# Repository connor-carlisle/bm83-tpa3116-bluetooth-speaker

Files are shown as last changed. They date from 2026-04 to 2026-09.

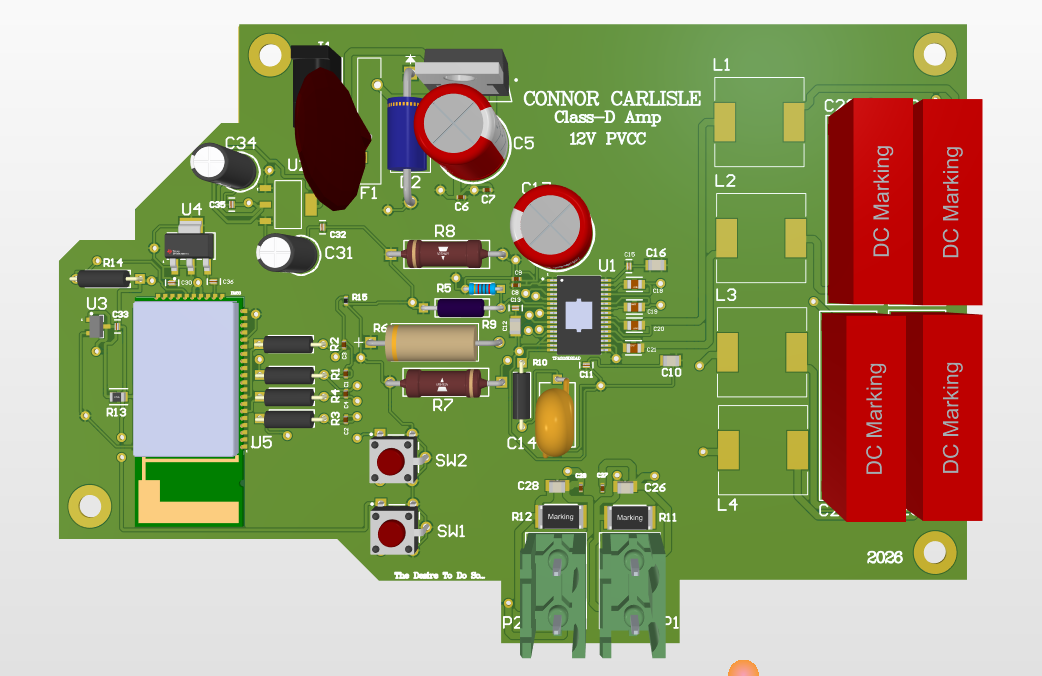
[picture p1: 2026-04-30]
images/PCB 3D Top View.png

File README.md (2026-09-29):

# Bluetooth Speaker — BM83 + TPA3116D2 Class D

A stereo Bluetooth speaker designed in Altium Designer around the **Microchip BM83** Bluetooth audio module and the **TI TPA3116D2DAD** Class D amplifier. Single-board design with a hierarchical schematic, mixed-signal grounding, and RF-aware antenna placement.

PCB 3D Top View

---

## Overview

This board is a fully integrated stereo Bluetooth speaker driver: it receives a Bluetooth audio stream, decodes it on the BM83 module, and drives a pair of speakers through a Class D amplifier — all on a single ~100 × 100 mm PCB.

The design is intentionally compact and inexpensive to fabricate (single-board, 2-layer, hand-solderable footprints throughout) while still respecting the discipline a mixed-signal RF audio board demands: clean separation of analog and high-current ground domains, careful output filtering on the Class D amplifier, and a defined antenna keep-out zone for the BM83's integrated chip antenna.

## Key specs

| Parameter | Value |
|---|---|
| Bluetooth module | Microchip BM83 (Bluetooth 5.0, A2DP / AVRCP) |
| Amplifier | TI TPA3116D2DAD — Class D, BTL stereo |
| Output power | Up to ~50 W/channel (supply-dependent) |
| Speaker configuration | Stereo, Bridge-Tied Load |
| Logic supply | Takes 12V PVCC input, 3.3 V regulator via LM1117-3.3 LDO + MCP111T-270E/TT reset supervisor for BM83|
| Board | 2-layer FR-4, ~100 × 100 mm |
| EDA | Altium Designer |

## Block diagram

  Power input ──┬──────────────────────► TPA3116D2 (Class D amp) ──► BTL LC filter ──► Speakers
                │
                └─► LM1117-3.3 LDO ──┬─► BM83 (Bluetooth audio) ──► (audio out to amp)
                                     │
                                     └─► MCP111T reset supervisor

## Design decisions

### Why the BM83
The BM83 is a fully-certified Bluetooth audio module — the alternative was building a Bluetooth stack on a bare BT chip, which is dramatically more work for a personal project and requires going through Bluetooth SIG certification. The BM83 ships with a complete stack, a stereo audio path, and an integrated chip antenna in a small footprint. The trade-off is less flexibility and a higher cost per unit, but it is the right choice for a single-board portfolio piece.

### Why the TPA3116D2DAD
Industry-standard Class D amplifier with strong documentation, stereo BTL configuration in a single chip, and well-understood thermal behavior. The DAD-suffix package (HTSSOP with PowerPad) is easier to hand-assemble than the alternative DAP package while still providing adequate thermal performance for the target output level.

### Power architecture
A single supply input feeds the TPA3116 directly and is regulated down to 3.3 V by an LM1117-3.3 LDO for the BM83. An MCP111T-270E/TT reset supervisor holds the BM83 in reset until the 3.3 V rail crosses its threshold, ensuring clean power-on-reset behavior. An LDO was chosen over a switcher for the BM83 supply specifically to avoid injecting switching noise into the Bluetooth radio's PLL.

### BTL output filter
The Class D switching outputs need an LC filter before reaching the speakers. Without one, you radiate the switching frequency directly through the speaker leads — which act as antennas — and you cause both EMI compliance problems and audible distortion. The filter is sized for the audio bandwidth and the target speaker impedance.

### Mixed-signal grounding
The board uses an **SGND / GND star ground** scheme: the analog return from the BM83 audio output and the high-current return from the speaker terminals are kept on separate copper pours and joined at a single point near the connector. Without this separation, speaker-current-induced ground bounce modulates the analog reference and shows up as audible noise in the amplified output.

### Antenna placement
The BM83's chip antenna is placed at the **board edge** with **copper pour exclusion** in the keep-out zone defined by the BM83 datasheet. Putting copper pour under or near the antenna detunes it and crushes the radiation pattern. This is one of those layout rules that's easy to miss but completely changes whether your Bluetooth actually works at usable range.

## Repository structure

```
.
├── README.md                       This file
├── LICENSE
├── altium/                         Raw Altium project source
├── outputs/
│   ├── gerbers/                    Manufacturing Gerbers + drill files (ZIP)
│   ├── bom/                        Bill of materials (CSV)
│   ├── pick-and-place/             Pick-and-place files
│   └── pdf/
│       ├── schematic.pdf           Browser-viewable schematic
│       └── fabrication-drawing.pdf Board outline and layer stack
├── docs/
│   ├── component-reference.md      Detailed component selection notes
│   └── design-notes.md             Extended design rationale
└── images/                         Renders and diagrams
```

## Viewing the design

Don't have Altium? You can still inspect everything:

- **[Schematic (PDF)](outputs/pdf/schematic.pdf)** — full hierarchical schematic
- **[Fabrication drawing (PDF)](outputs/pdf/fabrication-drawing.pdf)** — board outline, layer stack, mechanical dimensions
- **[Bill of materials](outputs/bom/)**
- **[3D renders](images/)**

To open the source files, clone the repo and open `altium/PCB1.PrjPcb` in Altium Designer (a free Altium Education license is available for students).

## Manufacturing

The Gerber set in `outputs/gerbers/` is fab-ready and tested-friendly with JLCPCB, PCBWay, and most North American fabs. Default specifications:

- 2-layer FR-4
- 1.6 mm thickness
- 1 oz copper
- HASL or ENIG finish

Most components are stocked at Digi-Key and Mouser. The BM83 has occasional supply constraints — check stock before placing an order.

## Status

- ✅ Design complete, schematic ERC clean
- ✅ Manufacturing outputs generated
- ✅ Prototype built
- 🔲 Bring-up and validation: output power, THD, idle noise

*Developed with AI assistance (Claude); design decisions and verification are my own.*

## Lessons learned

A few things that came out of this design that I'd carry forward to the next revision:

- **Reset supervisor is non-negotiable.** An earlier iteration tied the BM83 reset pin to the 3.3 V rail through a simple pull-up. The MCP111T was added after observing the BM83 occasionally powering up into an undefined state on slow rail rise. Explicit POR handling is cheap and worth it.
- **Signal grounding paid off.** Iterations with a single solid GND plane showed audible noise on the speakers that correlated with bass-heavy content — high-current speaker returns were modulating the analog reference. Splitting SGND from GND and tying them at a single point cleared it.
- **Antenna keep-out matters.** The first layout had ground pour right up to the BM83 antenna. Pulling the pour back to the manufacturer-defined keep-out improved Bluetooth range noticeably.
- **Checking data sheets prior to designing.** There were several times where I would design haphazardly, or lazily adding a footprint, and then end up checking the data sheet and realizing that the pin count is wrong, or the module is a different component than what I needed, etc.
- **Power route widths are non-negotiable and must be accounted for in the design.** When finishing the basic routing I soon realized afterwards that the routes all needed to be readjusted anyway to account for the increased width of the power routes, such as the 12V power supply and 3.3V regulator power.
- **Always expect to use more than one layer** While this seem obvious now, I assumed when making the schematic that I would be able to mathematically fit all routes together without crossing. Needless to say, I soon realized after starting the PCB design that this was impossible, at least for a project of this complexity.

## License

Released under the MIT License — see [LICENSE](LICENSE). You're free to use, modify, and distribute the design.

The Altium source files in this repository were created using an Altium Education student license. The design itself is yours under MIT, but you'll need your own Altium license (commercial or student) to open and modify the source files.

**No warranty.** This is a hobby/educational design. It has not been certified to any safety, EMC, or Bluetooth SIG standard. Building, powering, or distributing it is at your own risk — switching amplifiers can dissipate significant heat and Bluetooth radios are subject to regional regulatory requirements.

## Author

**Connor Carlisle** — Electrical Engineering, University of Mississippi
[GitHub](https://github.com/[connor-carlisle]) · [LinkedIn](https://linkedin.com/in/[connor-carlisle])

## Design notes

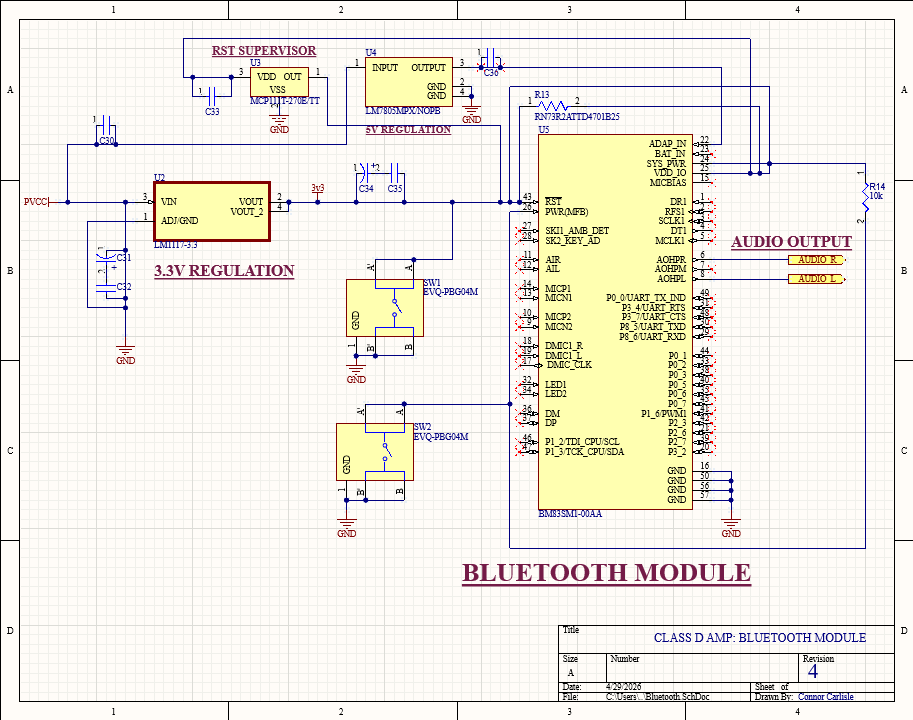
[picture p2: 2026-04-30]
images/Bluetooth Module Schematic Sheet.png

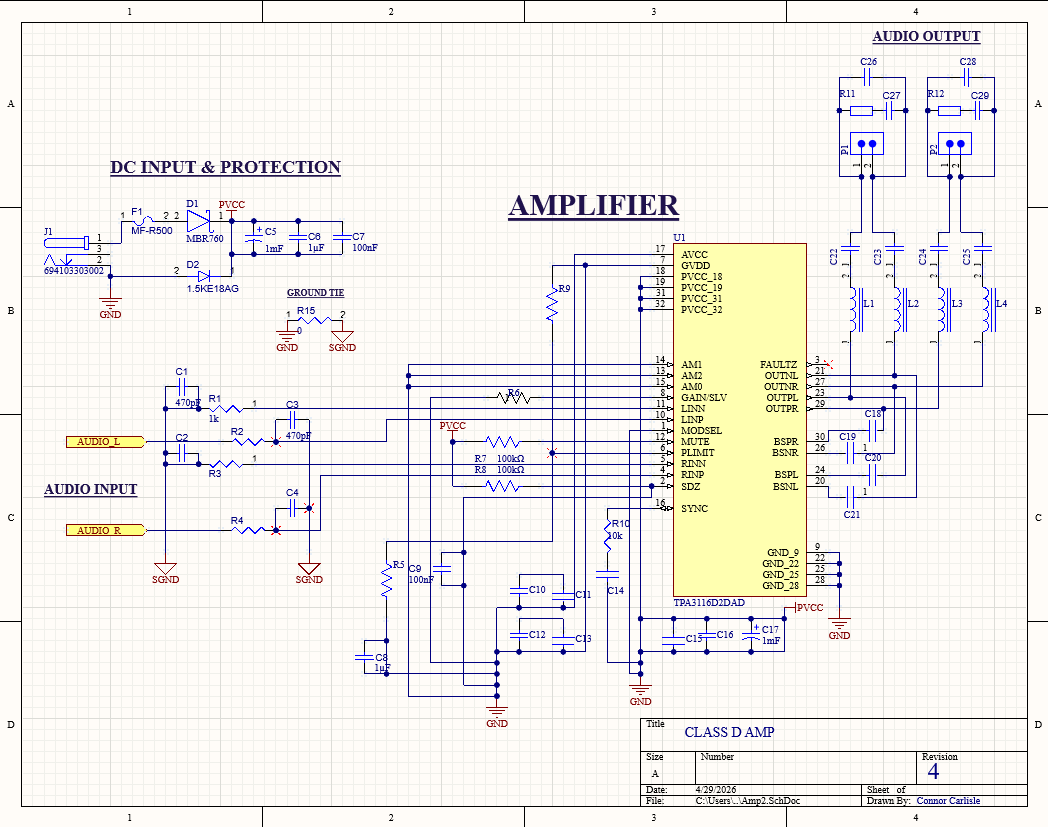
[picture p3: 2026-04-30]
images/Amplifier Schematic Sheet.png

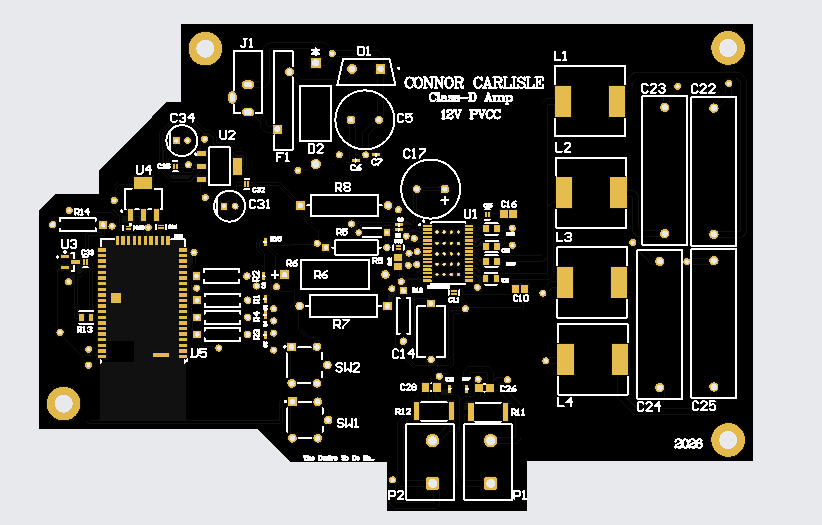
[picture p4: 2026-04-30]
images/JLCPCB PCB Viewer.png

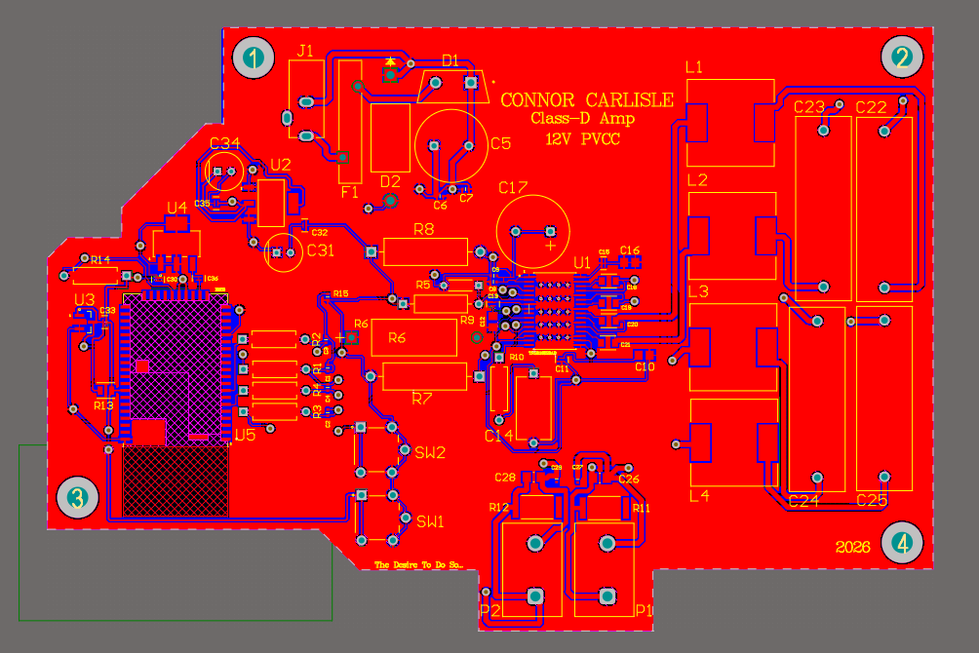
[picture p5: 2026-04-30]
images/PCB 2D Top View.png

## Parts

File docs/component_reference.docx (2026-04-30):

Bluetooth Speaker System

Component Reference Guide

Connor Carlisle • April 2026

This document maps every component in both schematic sheets to its function: what it does, why it is there, and how it works in context.

# Sheet 1: Bluetooth Module

## Power Regulation

Ref | Component | Function
U2 | LM1117-3.3 | Linear voltage regulator. Drops PVCC down to 3.3V for the BM83. Chosen because the BM83 requires a clean, low-noise 3.3V supply. The LM1117 requires a minimum output capacitance for stability.
U4 | LM7805MPX/NOPB | 5V linear regulator. Steps PVCC down to 5V, which then feeds U2. Two-stage regulation avoids excessive thermal dissipation in a single regulator when PVCC is 12V or higher.
U3 | MCP111T-270E/TT | Reset supervisor IC. Monitors the 3.3V rail and holds the BM83 RST pin low until the supply stabilizes above ~2.7V. Prevents the module from booting in a brownout state with undefined behavior.
C30 | Decoupling cap | Input decoupling on the LM1117-3.3. Stabilizes the voltage arriving at the regulator input and suppresses high-frequency noise on the supply line.
C31, C32 | Decoupling caps | Output decoupling on the LM1117-3.3. Required for regulator stability (LM1117 datasheet mandates a minimum output capacitance). Filters ripple on the 3.3V rail.
C33 | Decoupling cap | Decoupling on the MCP111T reset supervisor. Ensures the supervisor itself has a stable supply so its threshold detection is accurate.
C34, C35 | Decoupling caps | Input and output decoupling on the LM7805. Same principle: stabilize the 5V rail and filter switching noise before it reaches the next regulation stage.
C36 | Decoupling cap | Additional output filtering on the LM7805 output. Provides extra high-frequency noise rejection on the 5V rail.

## BM83 Bluetooth Module

Ref | Component | Function
U5 | BM83SM1-00AA | Bluetooth 5.0 audio module from Microchip. Receives Bluetooth audio stream, decodes it, and outputs analog stereo audio on AOHPR and AOHPL. Handles pairing, codec negotiation, and audio streaming autonomously.
R13 | RN73R2ATD4701B25 (4.7kΩ) | Precision pull-up resistor on the RST line. Holds RST high during normal operation so the module runs. The MCP111T overrides this and pulls RST low during power-up until the rail is stable.
R14 | 10kΩ resistor | Pull-up or biasing resistor on a configuration or status line of the BM83. Sets a defined logic state on the pin to avoid floating input behavior.
AOHPR | Audio output right | Analog right-channel audio output from the BM83. Becomes the AUDIO_R sheet port connecting to the amplifier sheet.
AOHPL | Audio output left | Analog left-channel audio output. Becomes AUDIO_L. Both outputs sit at a DC bias point set by AOHPM.
AOHPM | Audio output mid | Virtual ground reference for the headphone/line outputs. The audio signals swing symmetrically around this DC level.

## User Interface

Ref | Component | Function
SW1 | EVQ-PBG04M | Momentary tactile pushbutton connected to SK1_AMB_DET. Likely handles play/pause or pairing functions. Active-low: pin is pulled high by a pull-up, button press shorts it to GND. BM83 detects the falling edge.
SW2 | EVQ-PBG04M | Second tactile pushbutton connected to SK2_KEY_AD. Handles a second user function such as volume or mode select. Same active-low configuration with a pull-up resistor.

# Sheet 2: Class D Amplifier

## Power Input and Protection

Ref | Component | Function
J1 | 694103303002 | Barrel jack DC power connector. Entry point for the external power supply. Provides PVCC to the entire system.
F1 | MF-R500 | 500mA polyfuse (resettable fuse). If current exceeds the rating, the fuse heats up, its resistance increases dramatically, and current flow drops to safe levels. Resets automatically when it cools. Protects against short circuits downstream.
D1 | MBR760 | Schottky diode for reverse polarity protection. If the power supply is connected backwards, D1 blocks current and nothing is damaged. Schottky type chosen for its low forward voltage drop (~0.3V), which wastes less power than a standard silicon diode (~0.7V).
D2 | 1.5KE18A | TVS (transient voltage suppression) diode. Under normal conditions it is invisible (high impedance). When a voltage transient exceeds ~18V, the diode avalanches and clamps the voltage, shunting the spike energy to GND in picoseconds. Protects against supply transients, hot-plug events, and ESD.
C5 | 1mF bulk cap | Large reservoir capacitor on PVCC. Supplies instantaneous current during loud bass transients when the amplifier demand exceeds what the power supply can deliver in real time. Prevents the rail from sagging and causing audible distortion.
C6 | 1µF cap | Mid-frequency decoupling on PVCC. Bridges the gap between the bulk cap (low-frequency energy storage) and the small ceramic caps (high-frequency filtering).
C7 | 100nF cap | High-frequency decoupling on PVCC. Catches fast transients and switching noise that the larger caps are too slow (due to parasitic inductance) to absorb.

## Ground Management

Ref | Component | Function
RJ1 | GND-SGND tie resistor | Connects power ground (GND) to signal ground (SGND) at a single controlled point. Prevents noisy return currents from the Class D output stage from flowing through the sensitive audio input ground path. This star-ground approach is critical for low-noise audio design.

## Audio Input Path

Ref | Component | Function
C1 | 470pF cap | Part of the RC low-pass input filter on AUDIO_L. Combined with R1 (1kΩ), cutoff frequency is ~339kHz. Strips ultrasonic noise and RF interference from the BM83 output before it reaches the amplifier.
C2 | 470pF cap | Same RC low-pass filter on the complementary input or second channel path. Identical function to C1.
R1 | 1kΩ resistor | Series resistor in the RC input filter for AUDIO_L. Sets the filter cutoff with C1. Also limits current into the amplifier input if the signal source has a fault.
R2 | Resistor | Series resistor in the RC input filter for the right channel. Same function as R1.
Coupling caps (marked ‘1’) | DC blocking caps | Block the DC bias voltage from the BM83 audio outputs. The BM83 outputs sit at a DC operating point; these caps strip that DC and pass only the AC audio signal. Without them, the amplifier would see a DC offset and clip or be damaged. Also form a high-pass filter with the downstream bias resistors — the cap value sets the low-frequency cutoff, so it must be large enough to pass the full audio band including deep bass.
R3 | Bias resistor to SGND | After the coupling cap strips the BM83 DC bias, this resistor re-references the signal to signal ground (0V). Gives the AC audio signal a defined DC operating point at the amplifier input. Value is chosen high enough to avoid loading the signal source.
R4 | Bias resistor to SGND | Same function as R3 for AUDIO_R. Establishes the DC reference for the right channel input.
C3, C4 | Input caps | Additional filtering or coupling capacitors in the input signal path. Provide further noise rejection or DC isolation depending on placement.

## TPA3116D2DAD Amplifier IC

Ref | Component | Function
U1 | TPA3116D2DAD | Class D stereo audio amplifier from Texas Instruments. Takes analog audio inputs and produces a high-frequency PWM output that is filtered back to analog by the output LC networks. Class D topology achieves high efficiency (>90%) because the output transistors operate as switches (fully on or fully off), minimizing power dissipated as heat.
R6 | 5.6kΩ resistor | Configuration resistor near the input section. Sets a specific logic or bias state for one of the mode/gain selection pins on the TPA3116.
R7 | 100kΩ resistor | Connected to RINN (pin 4). Part of the input impedance and gain-setting network. Works with the AM pin states to define the amplifier gain.
R8 | 100kΩ resistor | Connected to RINP (pin 5). Mirrors R7 for the positive input of the right channel. Ensures balanced input impedance across both channels.
R10 | 10kΩ resistor | Pull-down (or pull-up) on SDZ (pin 2), the active-low shutdown pin. Determines whether the amplifier starts in shutdown or active mode on power-up. If pulled low, the amp is off until explicitly enabled.
AM0/AM1/AM2 | Pins 15, 13, 14 | Gain selection pins. Their logic states (tied high or low) select the amplifier gain from fixed options (20dB, 26dB, 32dB, 36dB). No external components needed — just the correct pin connections.
GAIN/SLV (pin 8) | Mode select | Selects master vs. slave mode. In a single-chip design, set to master. Also interacts with the gain mapping selected by the AM pins.
MODSEL (pin 12) | Mode select | Selects BTL (bridge-tied load) or PBTL (parallel bridge-tied load). BTL gives two independent stereo channels; PBTL combines both halves for one higher-power mono channel.
MUTE (pin 6) | Soft mute control | Logic-controlled mute. High = unmuted, low = muted. Can be tied permanently or controlled by the BM83 for click/pop suppression during power transitions.
PLIMIT (pin 5) | Power limit | Can be configured with a resistor divider to cap maximum output power, protecting speakers from being overdriven.
SYNC (pin 16) | Oscillator sync | Synchronization pin for the internal switching oscillator. In single-chip designs, typically left floating or tied per the datasheet recommendation.
FAULTZ (pin 3) | Fault output | Open-drain fault indicator. Goes low on overcurrent, overtemperature, or DC offset fault. Can drive an LED or signal the BM83 for status monitoring.

## Amplifier Power Decoupling

Ref | Component | Function
C8 | 1µF cap | Decoupling on AVCC (analog supply pin). AVCC powers the internal reference and bias circuits, so it needs very clean, low-noise power. R5 + C9 may form an RC filter to further isolate it from the noisy PVCC rail.
R5 + C9 | RC filter (100nF) | RC power filter on a sensitive supply or reference pin. The resistor isolates the pin from the main PVCC rail, and the cap filters locally, giving that pin its own ultra-clean supply. Common on AVCC or internal oscillator supply pins.
C10–C14 | Decoupling caps | Local decoupling on PVCC_18, PVCC_19, PVCC_31, PVCC_32, and GVDD. Multiple values cover different frequency ranges: 100nF for high-frequency transients, 1µF for mid-range, larger values for low-frequency ripple. Each power pin gets its own cap placed as close to the pin as physically possible.
C15, C16 | Decoupling caps | Additional power pin decoupling. Ensures every supply pin has local energy storage to handle switching current demands without voltage droop.
C17 | 1mF bulk cap | Second bulk reservoir near the amplifier power pins. Supplements C5 to provide energy during high-current transients at the amplifier side, reducing the effective distance to stored energy.

## Bootstrap Capacitors

Ref | Component | Function
C18 | Bootstrap cap (BSPR) | Bootstrap capacitor for the right-channel positive half-bridge. Charges through an internal diode when the low-side FET is on, then provides elevated gate drive voltage for the high-side FET. Without it, the high-side MOSFET cannot fully turn on, causing distortion and thermal stress.
C19 | Bootstrap cap (BSNR) | Bootstrap cap for the right-channel negative half-bridge. Same operating principle. Each half-bridge in the BTL output needs its own bootstrap cap.
C20 | Bootstrap cap (BSPL) | Bootstrap cap for the left-channel positive half-bridge.
C21 | Bootstrap cap (BSNL) | Bootstrap cap for the left-channel negative half-bridge. Typically 100nF ceramic. All four must be present for proper Class D operation.

## Output Section

Ref | Component | Function
OUTNL/OUTPL | Pins 21, 23 | BTL output pair for the left channel. The speaker connects between these two pins (not referenced to ground). The signal is a PWM waveform at ~600kHz switching frequency.
OUTNR/OUTPR | Pins 27, 29 | BTL output pair for the right channel. Same differential drive topology.
L1, L2 | Output inductors (left) | LC low-pass filter inductors for the left BTL output. Block the 600kHz switching frequency from reaching the speaker. Pass the audio-frequency content. Typical value: 22µH.
L3, L4 | Output inductors (right) | Same function for the right channel BTL output.
C22, C23 | Output filter caps (left) | Shunt remaining high-frequency switching ripple to ground after the inductors. Combined with the inductors, they form a second-order LC low-pass filter that reconstructs the analog audio waveform from PWM. Typical value: 680nF–1µF.
C24, C25 | Output filter caps (right) | Same function for the right channel output filter.
C26, C28 | Additional output caps | Extra filtering capacitors on the outputs. May be across the BTL output pair for differential filtering, reducing common-mode noise radiated through the speaker wires.
C27, C29 | Additional output caps | Complement C26/C28. Part of the differential output filter network.
R11 | Damping resistor (left) | Resistor in parallel with the output inductor. Prevents the LC filter from resonating at its natural frequency, which would create a peak in the frequency response and potential oscillation. Dissipates resonant energy as heat for a flat, stable response.
R12 | Damping resistor (right) | Same damping function for the right channel output filter. Ensures both channels have identical, well-damped frequency response.
P1, P2 | Speaker connectors | Output terminal blocks or connectors for the left and right speakers. The speaker connects across each BTL pair (not to ground).

## Signal Flow Summary

Power enters through J1, passes through F1 (overcurrent protection), D1 (reverse polarity), and D2 (transient suppression). PVCC feeds the TPA3116 amplifier directly and routes to the Bluetooth sheet where U4 and U2 step it down to 5V then 3.3V for the BM83. The BM83 receives a Bluetooth audio stream, decodes it, and outputs analog stereo on AOHPR/AOHPL. These signals pass through DC blocking caps (coupling capacitors), RC low-pass filters, and biasing resistors before arriving at the TPA3116 inputs. The TPA3116 amplifies the signal as a high-frequency PWM waveform, which the output LC filters reconstruct into analog audio for the speakers.

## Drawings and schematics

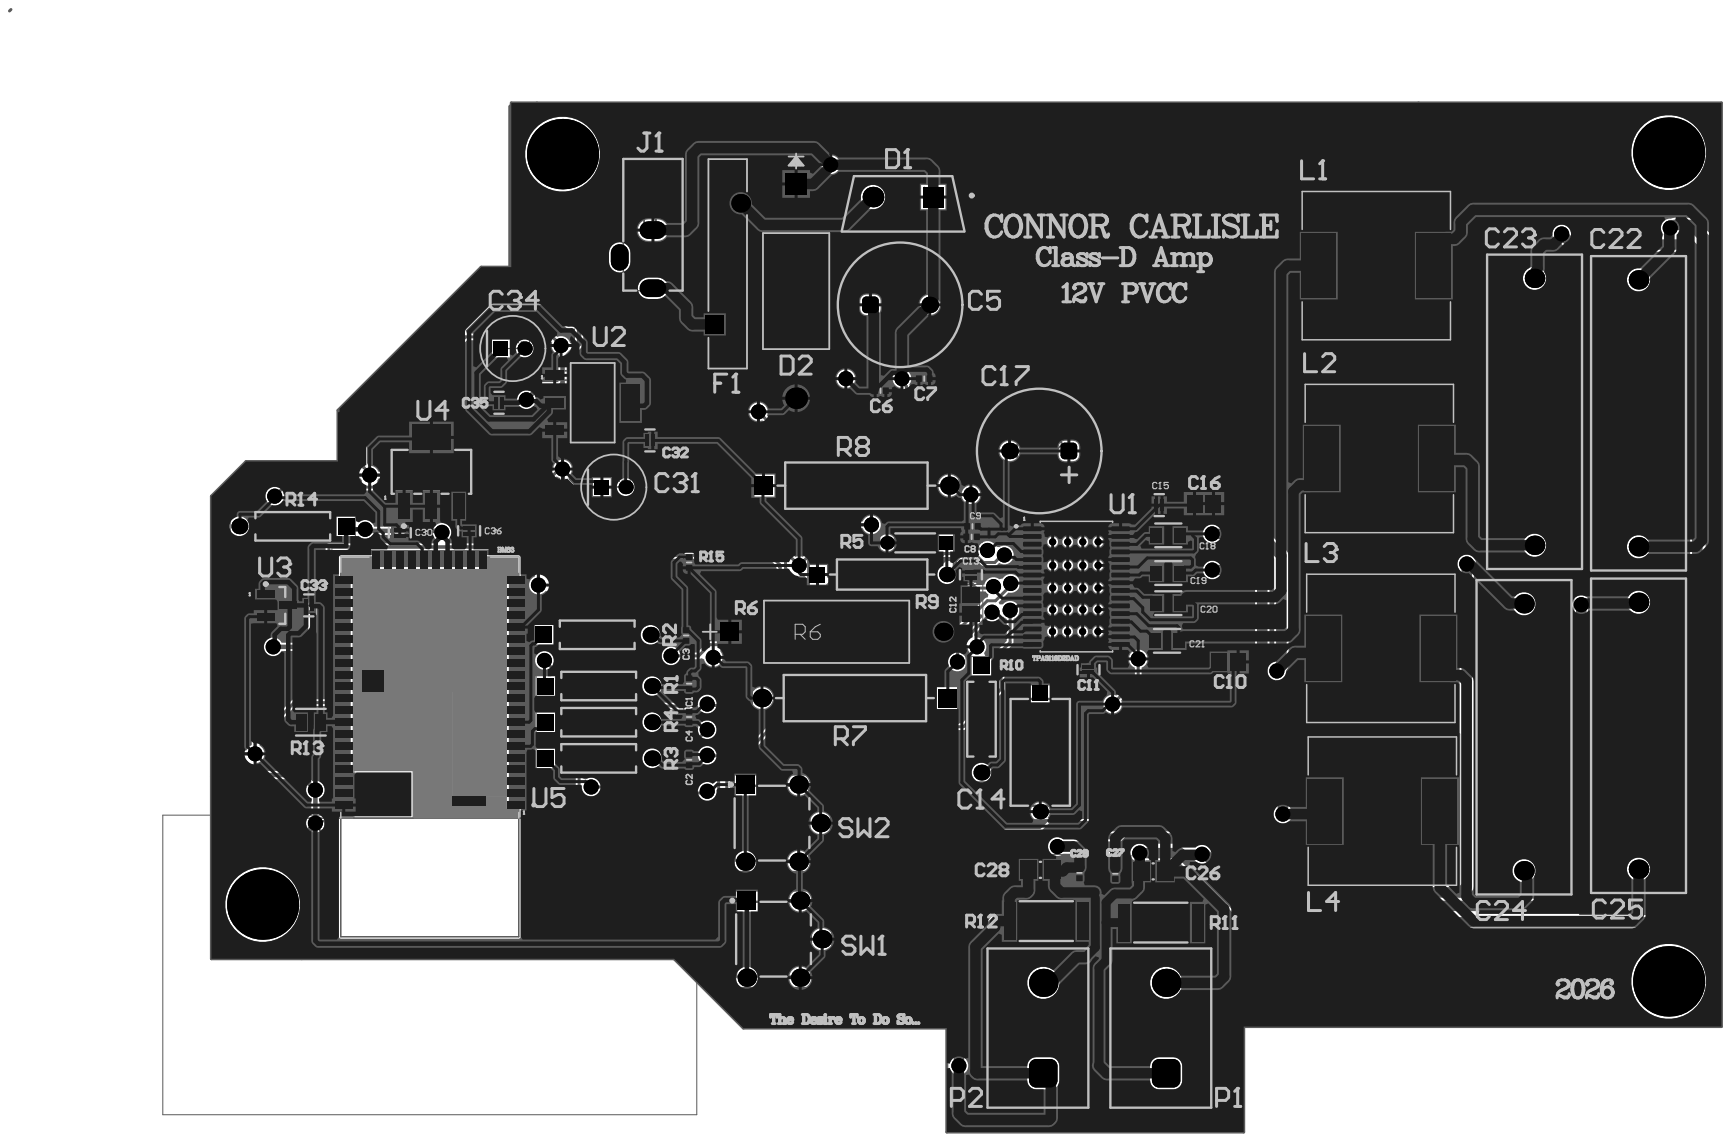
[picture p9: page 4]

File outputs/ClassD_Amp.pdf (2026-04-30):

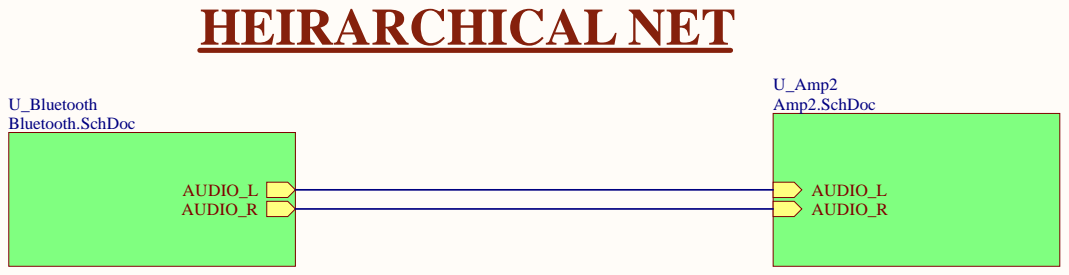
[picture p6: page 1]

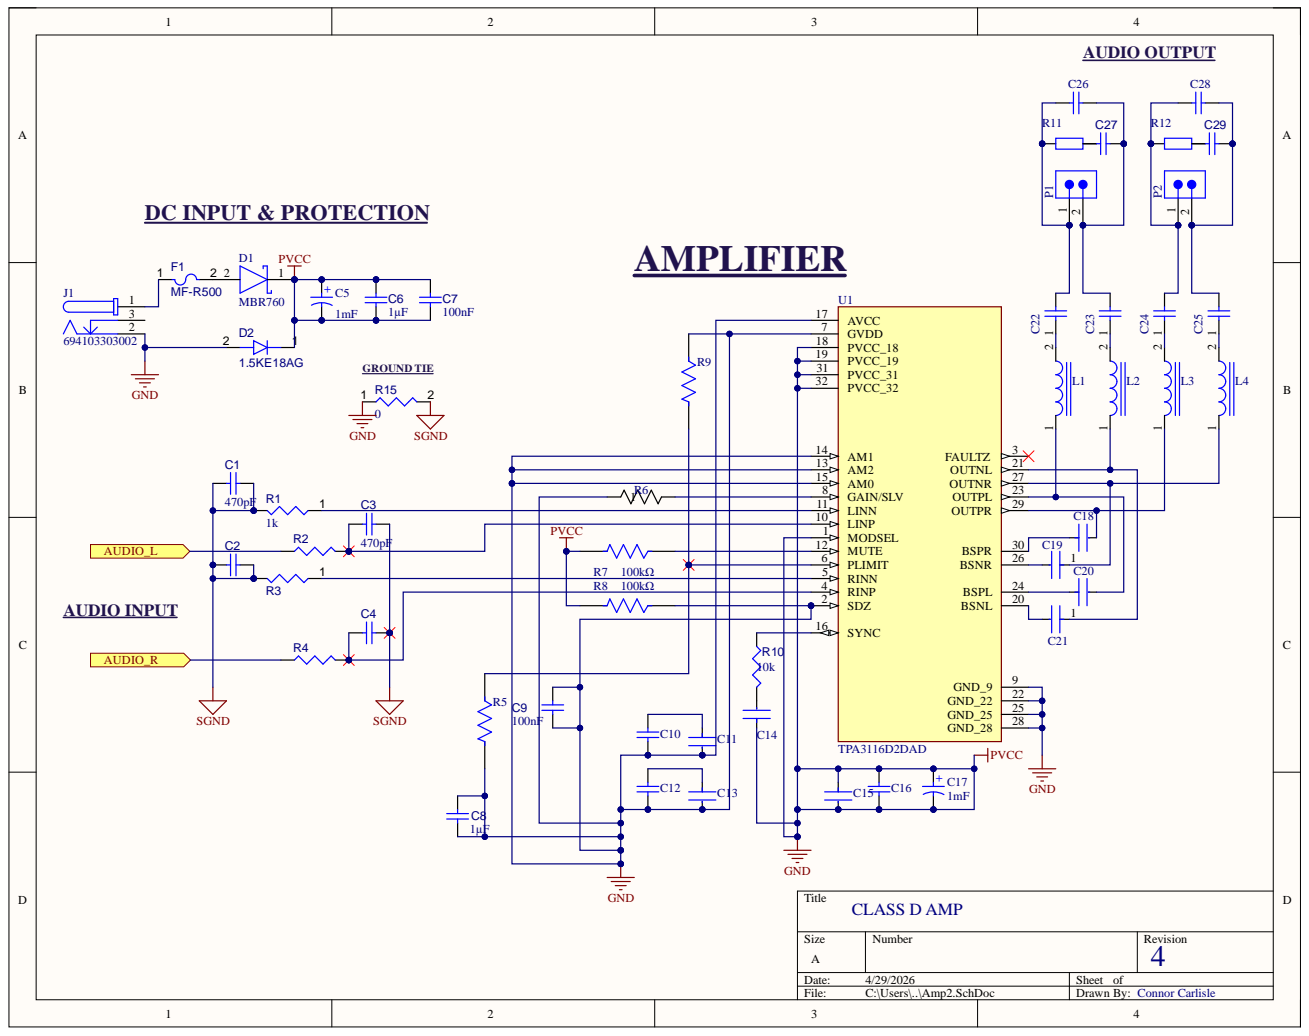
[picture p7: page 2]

GVDD 7
PVCC_18 18
PVCC_19 19
PVCC_31 31
PVCC_32 32

AM1 14
AM2 13
AM0 15

470pF | | PVCC | | | | MODSEL 1

R7 R8 | 100kΩ | | PLIMIT 6

RINN 5 RINP 4 | C20

C4 | | | SDZ 2 | 1

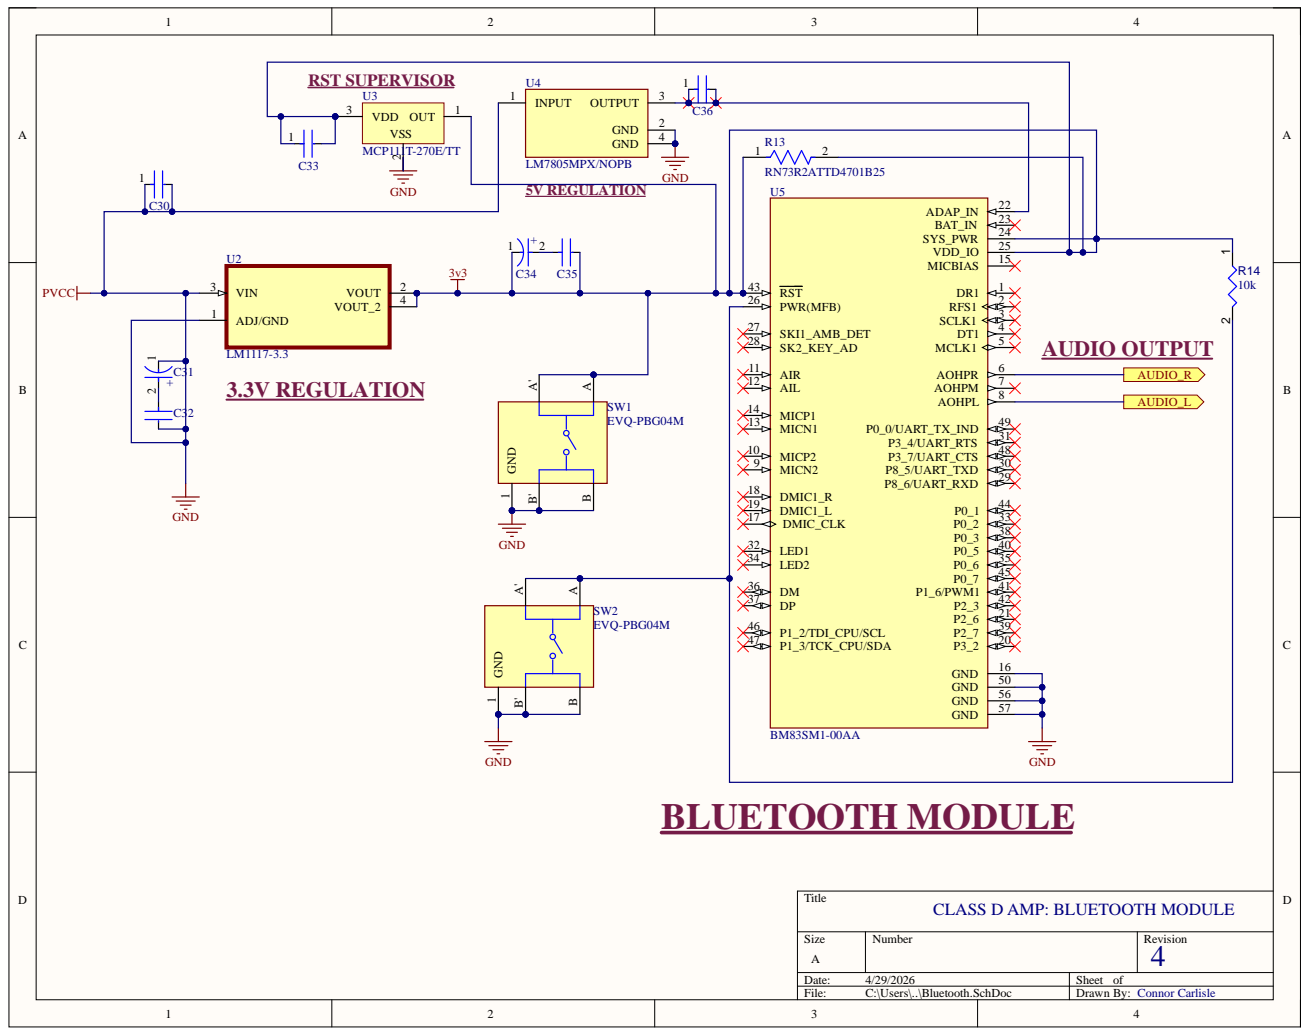
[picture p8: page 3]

ADJ/GND 1 | PWR(MFB) 26

SKI1_AMB_DET 27

CLASS D AMP: BLUETOOTH MODULE
